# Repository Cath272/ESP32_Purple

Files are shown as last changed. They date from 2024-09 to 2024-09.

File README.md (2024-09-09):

# ESP32_Purple

The ESP32 PURPLE was build because i wanted to design my own esp32 based microcontroller with a few extra features.

Features:
-Esp32 Module,

-CH343P usb to uart Ic,

-3.3V AMS117 power supply,

-USB TYPE-C port with c to c cable support, 

-MicroSD card slot,

-14Pin Connector for a ST7735 Display(0.5mm pitch),

PCB view:

Schematic:


Components Pinout:

LCD: DC:IO26 , MOSI:IO23, SCK:IO18, CS:IO5

MicroSD: MISO:IO19, SCK:IO18, MOSI:IO23 , CS_SD:IO5

Final Assembled product:
WhatsApp Image 2024-09-08 at 15 17 54_2ad6fa92

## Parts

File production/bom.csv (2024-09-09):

Designator | Footprint | Quantity | Value | LCSC Part #
C1, C2 | 0805 | 2 | 22uF
C3 | 0402 | 1 | 0.1uF
C4, C5 | 0402 | 2 | 1uF
C6 | 0402 | 1 | 100nF
C7 | CP_EIA-3528-15_AVX-H_Pad1.50x2.35mm_HandSolder | 1 | 100uF 6.3V
D1, D3 | 0603 | 2 | LED
D2 | D_SOD-323 | 1 | 1N5819WS
J1 | USB_C_Receptacle_GCT_USB4105-xx-A_16P_TopMnt_Horizontal | 1 | USB_C_Receptacle_USB2.0_16P
J3, J4 | PinSocket_1x20_P2.54mm_Vertical | 2 | Conn_01x20_Socket
J5 | SUNTECH_ST-TF-003A | 1 | Micro_SD_Card
J6 | Hirose_FH12-14S-0.5SH_1x14-1MP_P0.50mm_Horizontal | 1 | 5034801400
LCD RST, SW2, SW3 | SW_SPST_PTS810 | 3 | SW_Push
Q1, Q2 | SOT-23 | 2 | BC817
R1 | 0402 | 1 | 1.5k
R10, R12, R4, R5 | 0402 | 4 | 10K
R11, R13, R15, R9 | 0402 | 4 | 470
R2, R3, R8 | 0402 | 3 | 5.1k
R6 | 0402 | 1 | 1K
R7 | 0402 | 1 | 7.5R
U1 | ESP32-WROOM-32D | 1 | ESP32-WROOM-32D
U2 | SOT-223-3_TabPin2 | 1 | AMS1117-3.3
U3 | TQFN-16-1EP_3x3mm_P0.5mm_EP1.6x1.6mm | 1 | CH343P

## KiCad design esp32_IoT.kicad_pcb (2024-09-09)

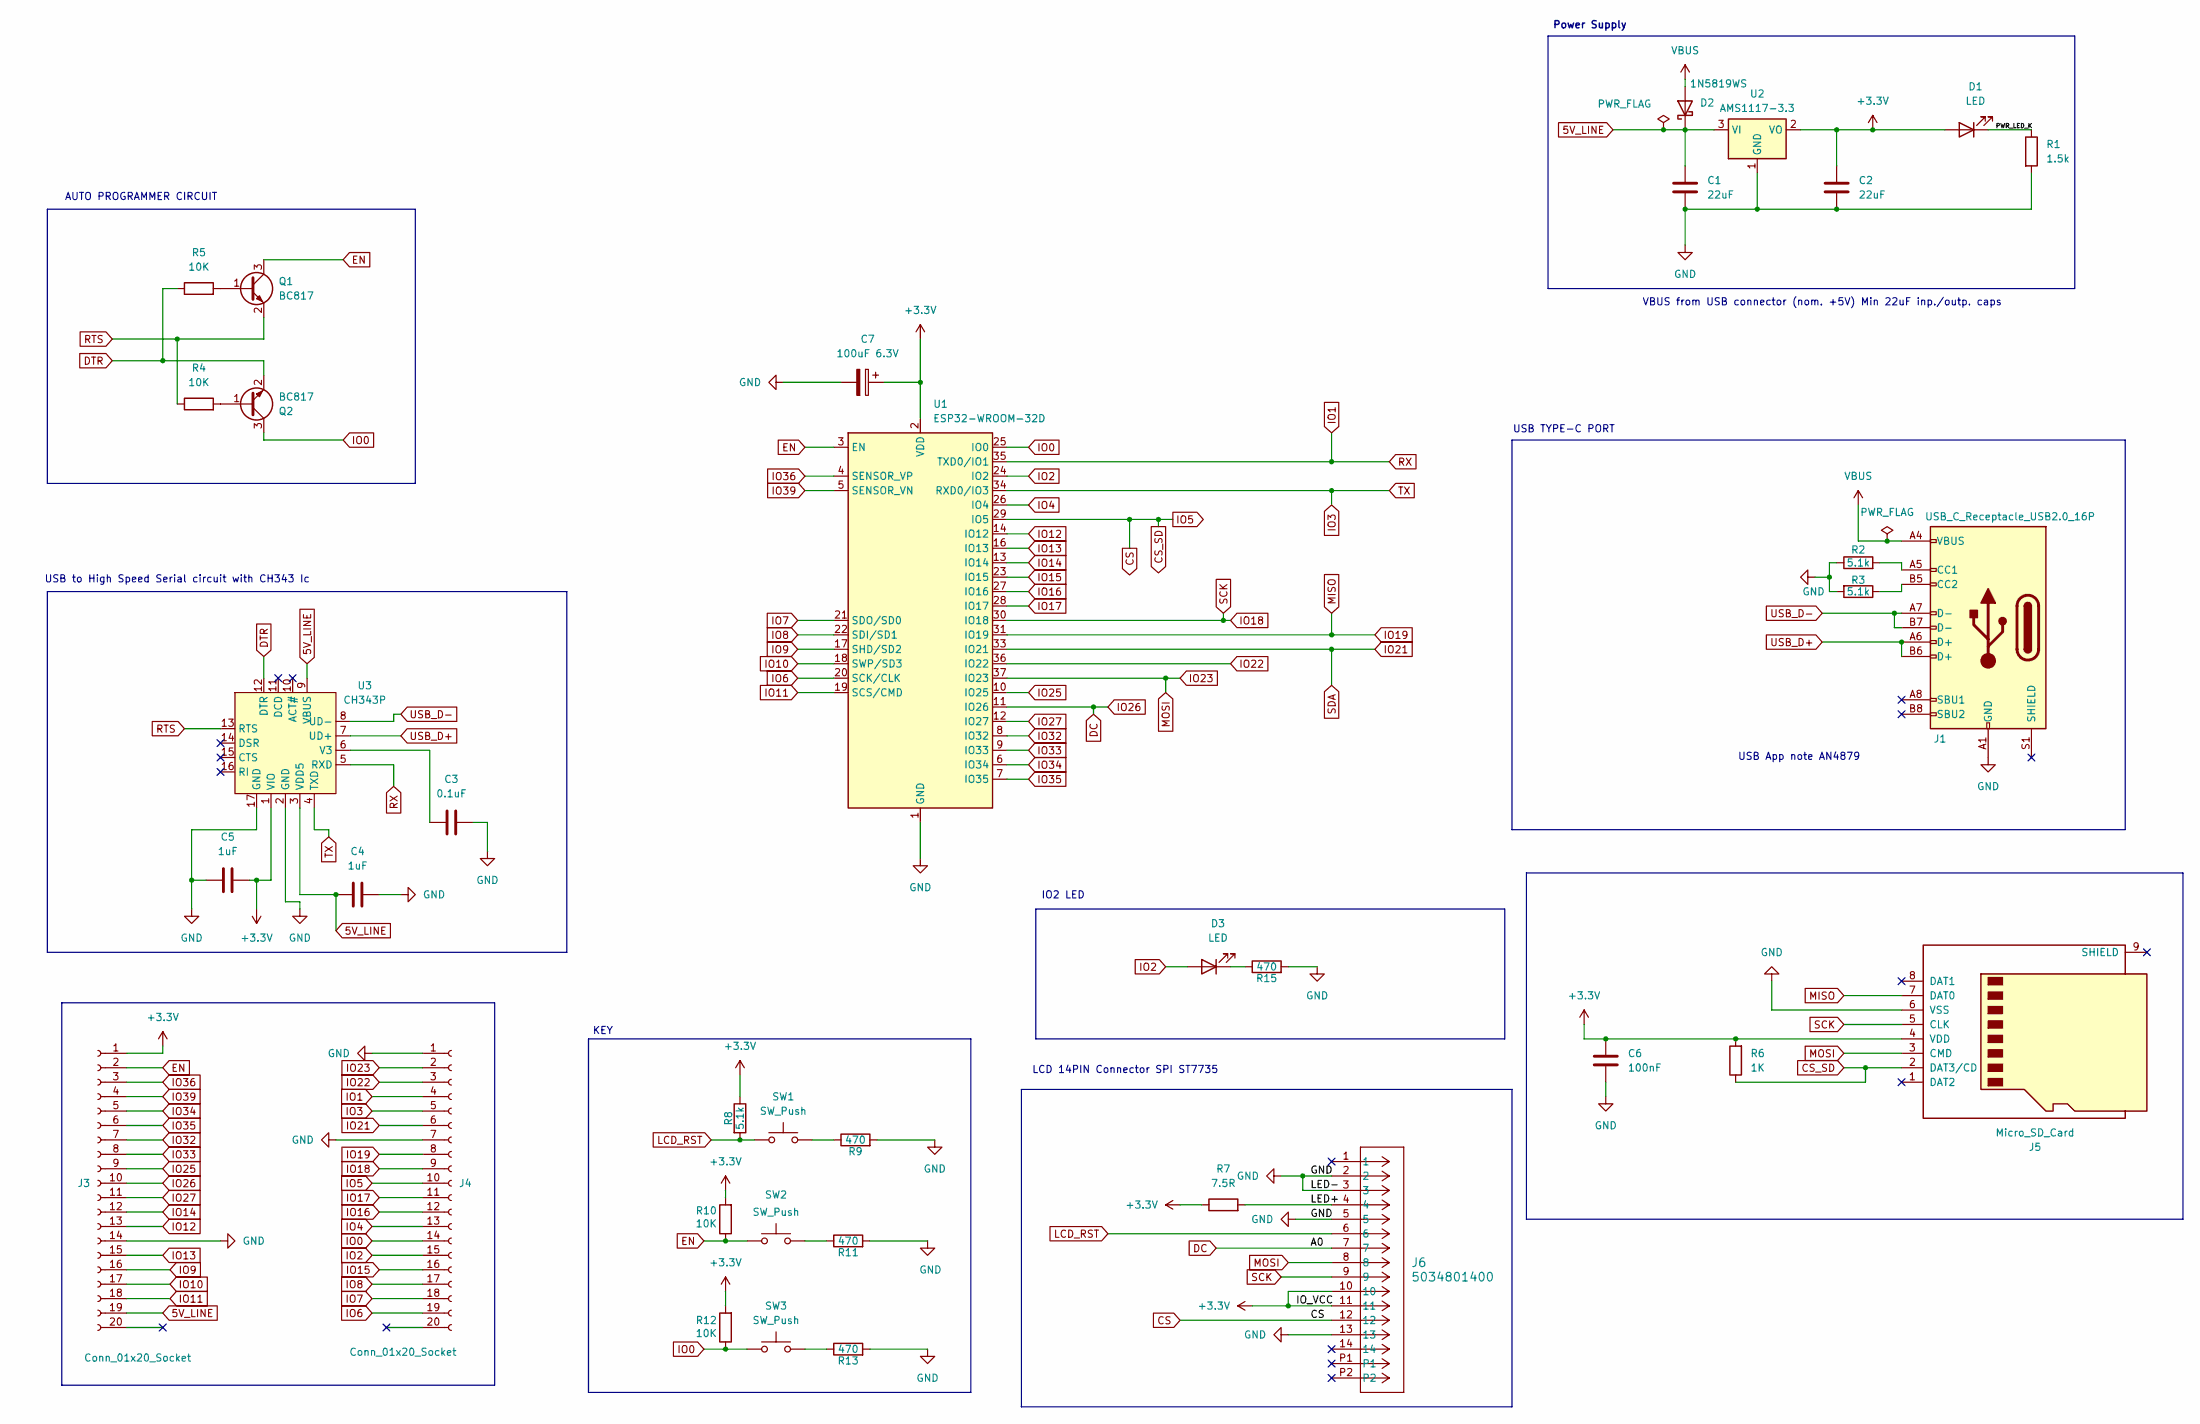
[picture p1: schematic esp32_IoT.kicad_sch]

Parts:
C1, C2: 22uF; C_0805_2012Metric
C3: 0.1uF; C_0402_1005Metric
C4, C5: 1uF; C_0402_1005Metric
C6: 100nF; C_0402_1005Metric_Pad0.74x0.62mm_HandSolder
C7: 100uF 6.3V; CP_EIA-3528-15_AVX-H_Pad1.50x2.35mm_HandSolder
D1, D3: LED; LED_0603_1608Metric
D2: 1N5819WS; D_SOD-323
J1: USB_C_Receptacle_USB2.0_16P; USB_C_Receptacle_GCT_USB4105-xx-A_16P_TopMnt_Horizontal
J3, J4: Conn_01x20_Socket; PinSocket_1x20_P2.54mm_Vertical
J5: Micro_SD_Card; SUNTECH_ST-TF-003A
J6: 5034801400; Hirose_FH12-14S-0.5SH_1x14-1MP_P0.50mm_Horizontal
Q1, Q2: BC817; SOT-23
R1: 1.5k; R_0402_1005Metric
R2, R3, R8: 5.1k; R_0402_1005Metric
R4, R5, R10, R12: 10K; R_0402_1005Metric
R6: 1K; R_0402_1005Metric
R7: 7.5R; R_0402_1005Metric
R9, R11, R13, R15: 470; R_0402_1005Metric
SW1, SW2, SW3: SW_Push; SW_SPST_PTS810
U1: ESP32-WROOM-32D
U2: AMS1117-3.3; SOT-223-3_TabPin2
U3: CH343P; TQFN-16-1EP_3x3mm_P0.5mm_EP1.6x1.6mm

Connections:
5V_LINE: C1.1, C4.1, D2.1 (K), J3.19, U2.3 (VI), U3.3 (VDD5), U3.9 (VBUS)
+3.3V: C2.1, C5.2, C6.1, C7.1, D1.2 (A), J3.1, J5.4 (VDD), J6.10, J6.11, R6.2, R7.1, R8.1, R10.2, R12.2, U1.2 (VDD), U2.2 (VO), U3.1 (VIO)
/LED+: J6.4, R7.2
/PWR_LED_K: D1.1 (K), R1.1
CS: J4.10, J5.2 (DAT3/CD), J6.12, R6.1, U1.29 (IO5)
DC: J3.10, J6.7, U1.11 (IO26)
DTR: Q2.2 (E), R5.1, U3.12 (DTR)
EN: J3.2, Q1.3 (C), R10.1, SW2.1, U1.3 (EN)
GND: C1.2, C2.2, C3.2, C4.2, C5.1, C6.2, C7.2, J1.A1 (GND), J1.A12 (GND), J1.B1 (GND), J1.B12 (GND), J3.14, J4.1, J4.7, J5.6 (VSS), J6.2, J6.3, J6.5, J6.13, R1.2, R2.1, R3.2, R9.2, R11.2, R13.2, R15.2, U1.1 (GND), U1.15 (GND), U1.38 (GND), U1.39 (GND), U2.1 (GND), U3.2 (GND), U3.17 (GND)
IO0: J4.14, Q2.3 (C), R12.1, SW3.1, U1.25 (IO0)
IO1: J4.4, U1.35 (TXD0/IO1), U3.5 (RXD)
IO2: D3.2 (A), J4.15, U1.24 (IO2)
IO3: J4.5, U1.34 (RXD0/IO3), U3.4 (TXD)
IO4: J4.13, U1.26 (IO4)
IO6: J4.19, U1.20 (SCK/CLK)
IO7: J4.18, U1.21 (SDO/SD0)
IO8: J4.17, U1.22 (SDI/SD1)
IO9: J3.16, U1.17 (SHD/SD2)
IO10: J3.17, U1.18 (SWP/SD3)
IO11: J3.18, U1.19 (SCS/CMD)
IO12: J3.13, U1.14 (IO12)
IO13: J3.15, U1.16 (IO13)
IO14: J3.12, U1.13 (IO14)
IO15: J4.16, U1.23 (IO15)
IO16: J4.12, U1.27 (IO16)
IO17: J4.11, U1.28 (IO17)
IO18: J4.9, J5.5 (CLK), J6.9, U1.30 (IO18)
IO19: J4.8, J5.7 (DAT0), U1.31 (IO19)
IO21: J4.6, U1.33 (IO21)
IO22: J4.3, U1.36 (IO22)
IO23: J4.2, J5.3 (CMD), J6.8, U1.37 (IO23)
IO25: J3.9, U1.10 (IO25)
IO27: J3.11, U1.12 (IO27)
IO32: J3.7, U1.8 (IO32)
IO33: J3.8, U1.9 (IO33)
IO34: J3.5, U1.6 (IO34)
IO35: J3.6, U1.7 (IO35)
IO36: J3.3, U1.4 (SENSOR_VP)
IO39: J3.4, U1.5 (SENSOR_VN)
LCD_RST: J6.6, R8.2, SW1.1; also elsewhere on the board
unnamed: D3.1 (K), R15.1
unnamed: J1.A5 (CC1), R2.2
unnamed: J1.B5 (CC2), R3.1
unnamed: Q1.1 (B), R5.2
unnamed: Q2.1 (B), R4.2
unnamed 45: R9.1, SW1.2; also elsewhere on the board
unnamed: R11.1, SW2.2
unnamed: R13.1, SW3.2
unnamed: C3.1, U3.6 (V3)
RTS: Q1.2 (E), R4.1, U3.13 (RTS)
USB_D+: J1.A6 (D+), J1.B6 (D+), U3.7 (UD+)
USB_D-: J1.A7 (D-), J1.B7 (D-), U3.8 (UD-)
VBUS: D2.2 (A), J1.A4 (VBUS), J1.A9 (VBUS), J1.B4 (VBUS), J1.B9 (VBUS)

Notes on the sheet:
LCD 14PIN Connector SPI ST7735
KEY
IO2 LED
USB to High Speed Serial circuit with CH343 Ic
AUTO PROGRAMMER CIRCUIT
VBUS from USB connector (nom. +5V) Min 22uF inp./outp. caps
USB App note AN4879
Power Supply
USB TYPE-C PORT

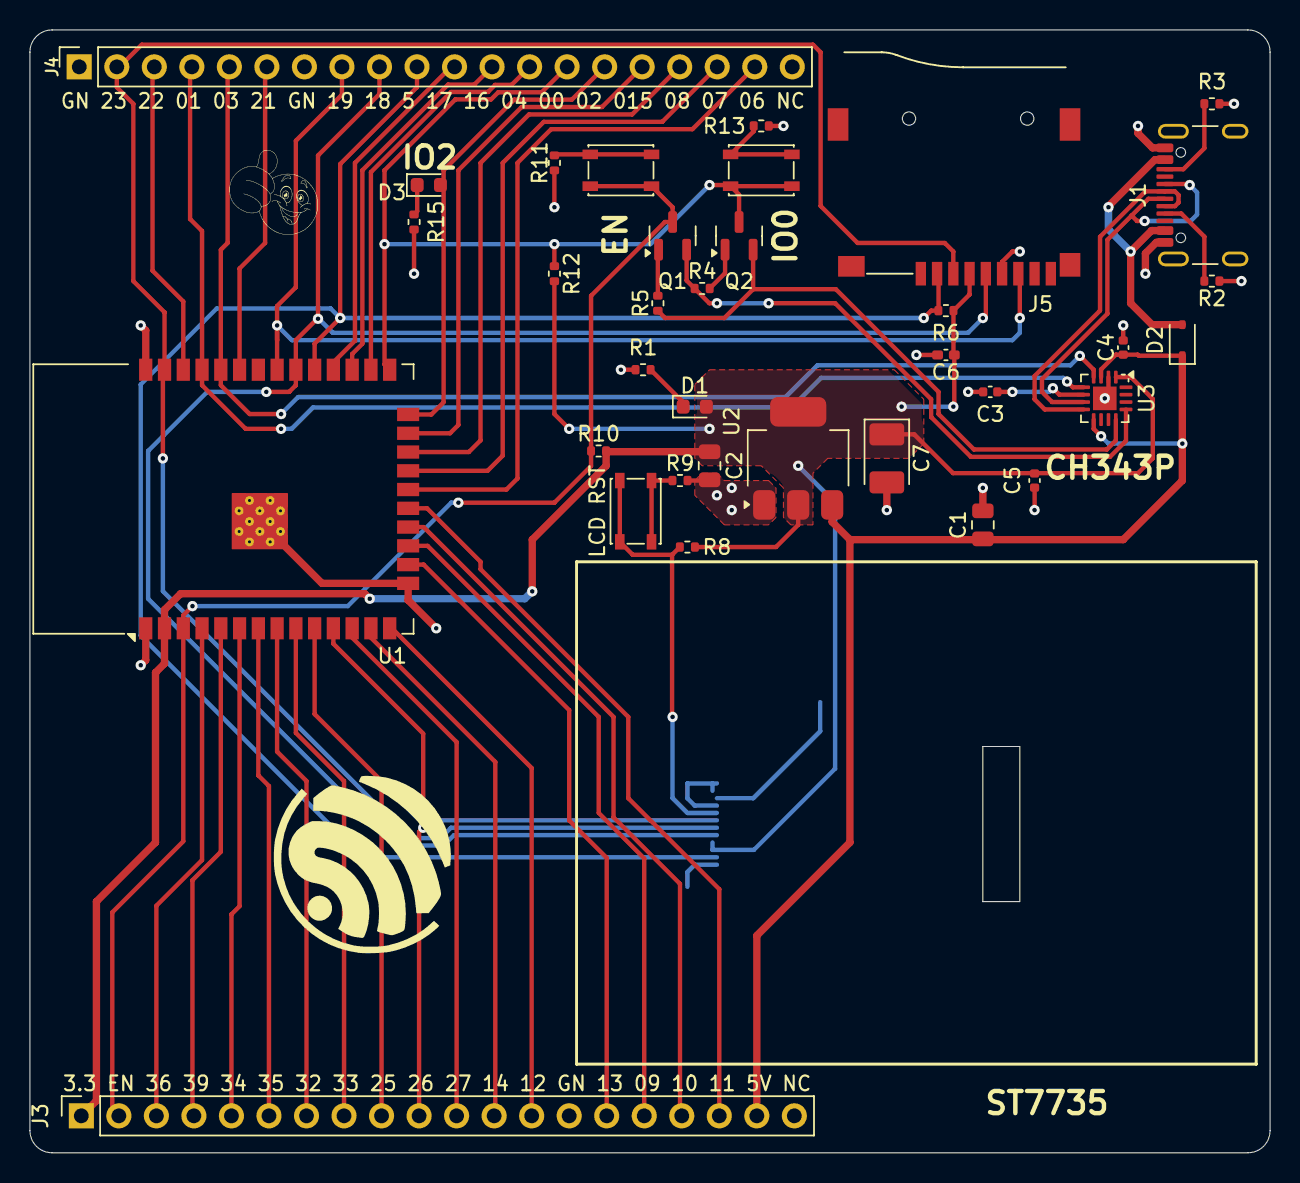
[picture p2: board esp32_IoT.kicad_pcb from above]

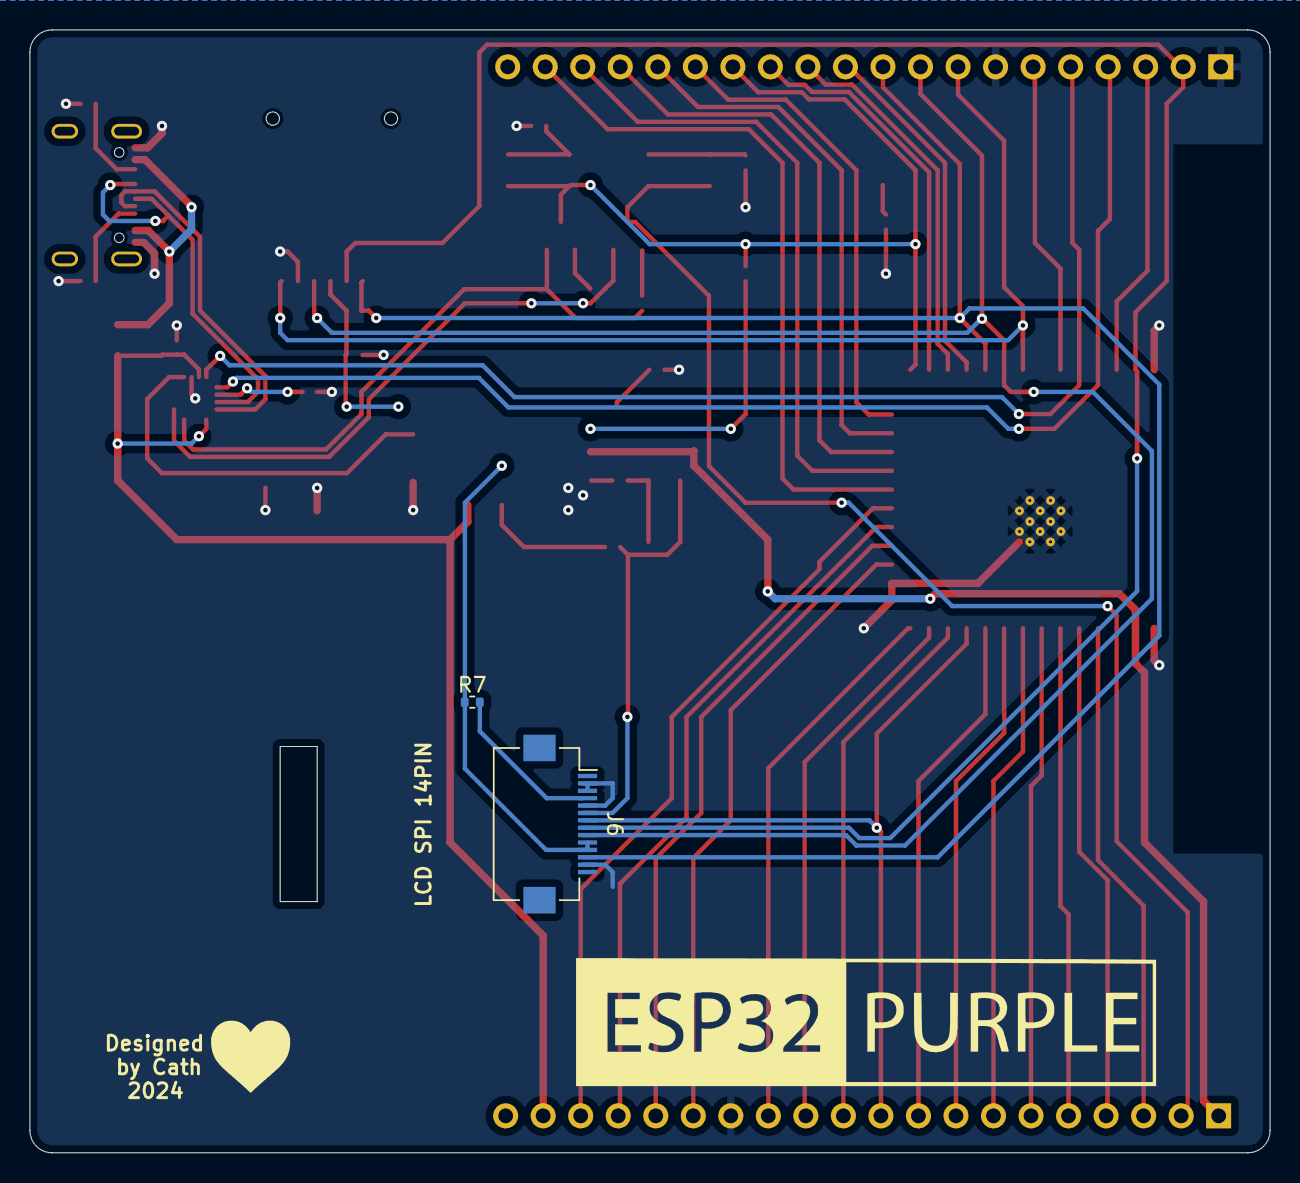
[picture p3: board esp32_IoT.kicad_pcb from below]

Board: 2 copper layers, 83.9 x 76.0 mm, 37 parts (2 on the bottom side), 53 nets.

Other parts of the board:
LCD RST: SW_Push; SW_SPST_PTS810

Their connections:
LCD_RST: LCD RST.1; also elsewhere on the board
unnamed 45: LCD RST.2; also elsewhere on the board
